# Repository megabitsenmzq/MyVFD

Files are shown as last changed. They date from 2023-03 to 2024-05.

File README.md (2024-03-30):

# MyVFD - A 9-Digit VFD Info Station ([Demo](https://www.youtube.com/watch?v=nbPkMLYwmgs))

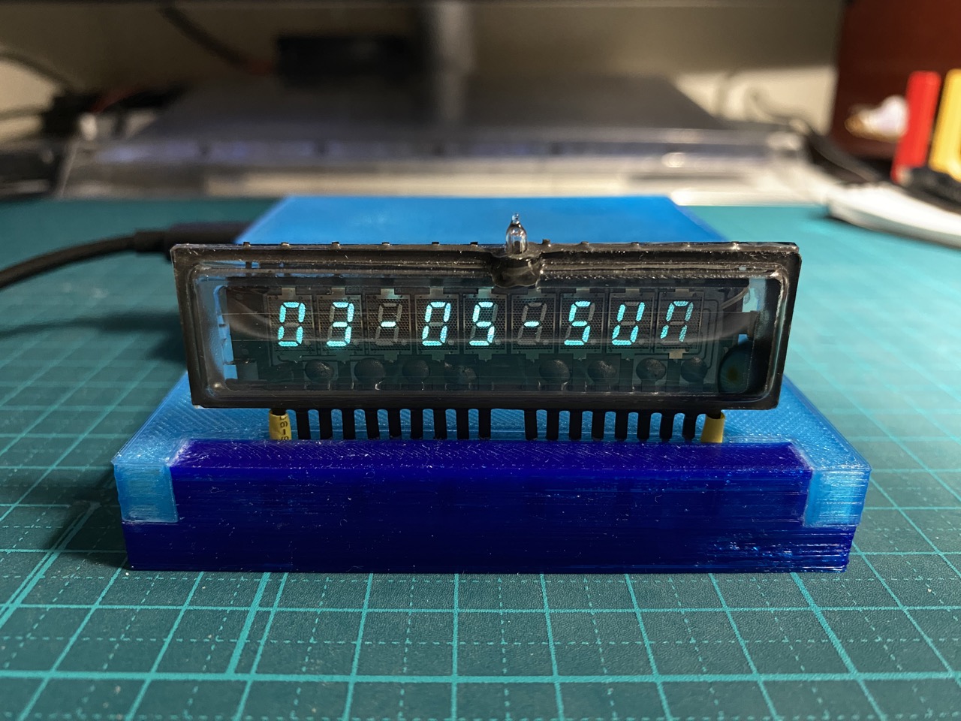
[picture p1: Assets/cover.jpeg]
Cover


Last year, I got an old Sharp EL-8109 calculator. Which uses a 9-digit Futaba 9-ST-08A VFD display. The calculator still works, but the shell is in bad shape, making it worth almost nothing. So I decided to use the screen inside to make something useful and look good.

This is the first hardware project I've ever made, so maybe I will do something wrong. Since I'm not a native English speaker, if you find any strange grammar, it's possibly my fault.

## What is a VFD

VFD means vacuum fluorescent display. Widely used in DVDs, radios, cassette decks, and so on. VFD screens look bright and visible from all angles. Making them the best choice for these devices. Today you can still see VFD screens in POS machines.

VFD

But LCD screens are becoming a better choice these days, and VFDs are no longer popular. Today, the green color of VFD screens gives them a retro vibe. If you want to see more beautiful VFDs, I recommend you watch this YouTube video by Posy: [VFD Displays](https://www.youtube.com/watch?v=PkPSDOjhxwM).

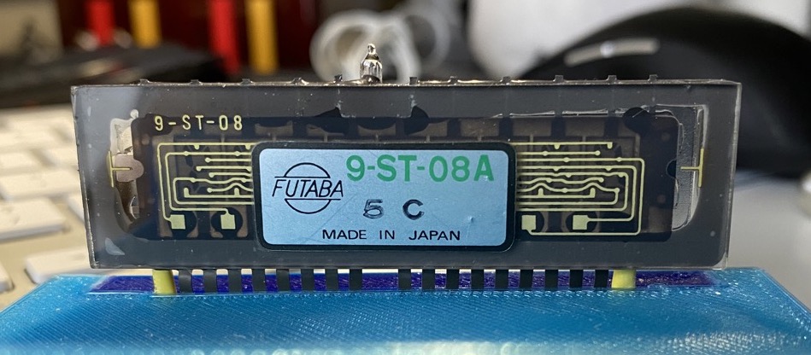
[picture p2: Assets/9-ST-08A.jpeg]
9-ST-08A


The screen 9-ST-08A was used in a variety of calculators around the 1970s, like Sanyo CX-8032 or Unisonic 1040. The company [Futaba (双葉電子工業株式会社)](https://www.futaba.co.jp/product/vfd) was Founded in 1948, making vacuum tubes and related things. They produced VFD screens until the end of 2021. Now they are moving on to newer display technologies.

## How to use the screen

This screen is too old, so it's almost impossible to find the datasheet. But most VFD screens are using the same structure. We can find out the pinout by ourselves.

This image from Futaba's website shows the basic structure of a VFD screen.

VFD Structure

VFD screens are very similar to vacuum tubes. Mainly, we have filaments, grids, and anodes. Filaments are very thin wires. They provide heat and a negative charge to the system. Anodes and grids provide high-voltage positive charge. Electrons will fly from filaments, pass the grids, and hit the anodes when they are both powered. Then you can see the beautiful green light from the phosphor.

VFD Structure 2

On a VFD screen. The pins on both sides are typically filament pins. They require a voltage of around 3V. And because we need a negative charge on the filament, the side near the positive pin will look dim. So it's best to power it with AC. This can ensure the screen lights evenly and extend its life. ~~Since I want to have a relatively small package on the final product. This time I will just use DC to power the screen.~~

I'm using a square wave as the AC power for the filament. First, I generate a 50% PWM signal from a pin. Then use a NOT gate to generate an inverted signal. Feed both signals to an H-bridge, there so we can have a square wave from about +5V to -5V.

Using a potentiometer to lower the voltage, adjust it to a proper value. When changing the voltage to the filament, you should keep an eye on the filament wires. If they start to glow, turn down the voltage immediately. Otherwise, the wires can start to melt and break. You might need to turn off all lights in your room to focus on this. You should let the voltage be just below the point which lets the filament glow.

After wiring the filament properly, we can start to take a look at other pins. Anodes and grids require a relatively high voltage. To provide this voltage, you need a step-up DC/DC converter. Connect the converter ground to the common ground, and use the high voltage to probe the pins. You need to connect both an anode pin and a grid pin to turn one segment on. Since I have a small screen that doesn't require such a high voltage to just light, I can use 5V for probing.

By probing you will know which pin is connected to which part of the screen. You can also check if there is a schematic printed behind the screen, like the image above.

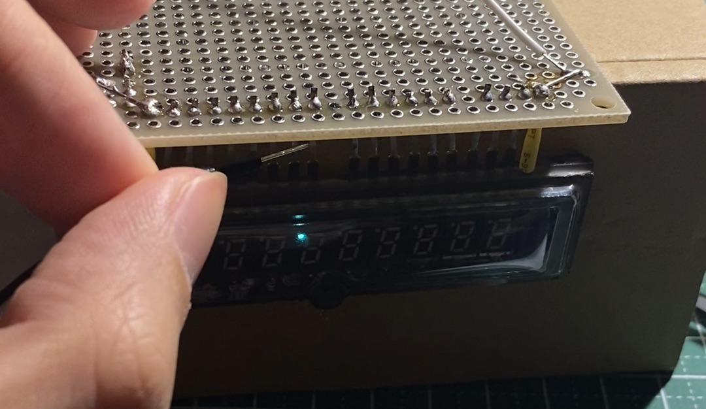
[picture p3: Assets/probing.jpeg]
Probing


## Build the circuit

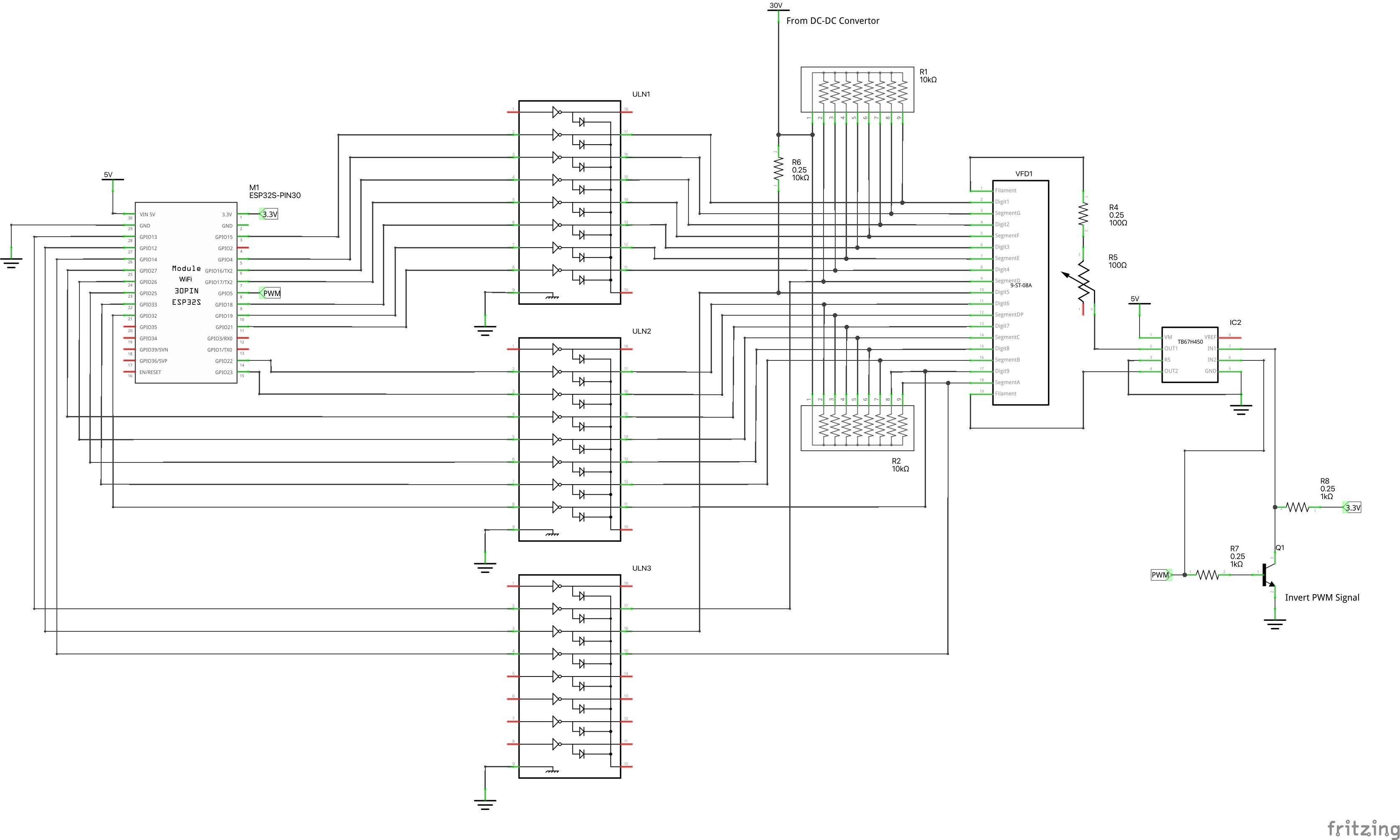
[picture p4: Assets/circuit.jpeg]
Circuit


In this circuit, I'm using Darlington Transistor Arrays (ULN2803) to control the screen. When the input pin of a transistor is low, the current goes through a 10K pull-up resistor and then the screen. When the input pin is high, it goes through the resistor and the transistor to the ground.

I have referenced [this](https://www.instructables.com/A-Simple-Driver-for-VFD-Displays/) design beforehand. In the schematic, it says the common pin of the ULN2803 should connect to the ground. However, after reading the datasheet and testing, I found this pin should not connect to anything. And the GND pin should be grounded.

I also found that the first transistor in the ULN2803 has a different behavior than others. When the input pin 1 is high, all the other transistors in the array will be turned on too. I don't understand why, but I can simply ignore the first pin. Tell me why if you know the reason.

On the ESP32 side. I'm using almost all the GPIO pins. but specifically left D2 behind. Because D2 is also connected to the onboard LED.

On the right side, you can see the AC power circuit. When the first time I made this project, I used to have DC power on the filament. Then I managed to find an easy way to do this, and the footprint is relatively small.

| Testing with the original board | Soldering | Soldering |
| --- | --- | --- |
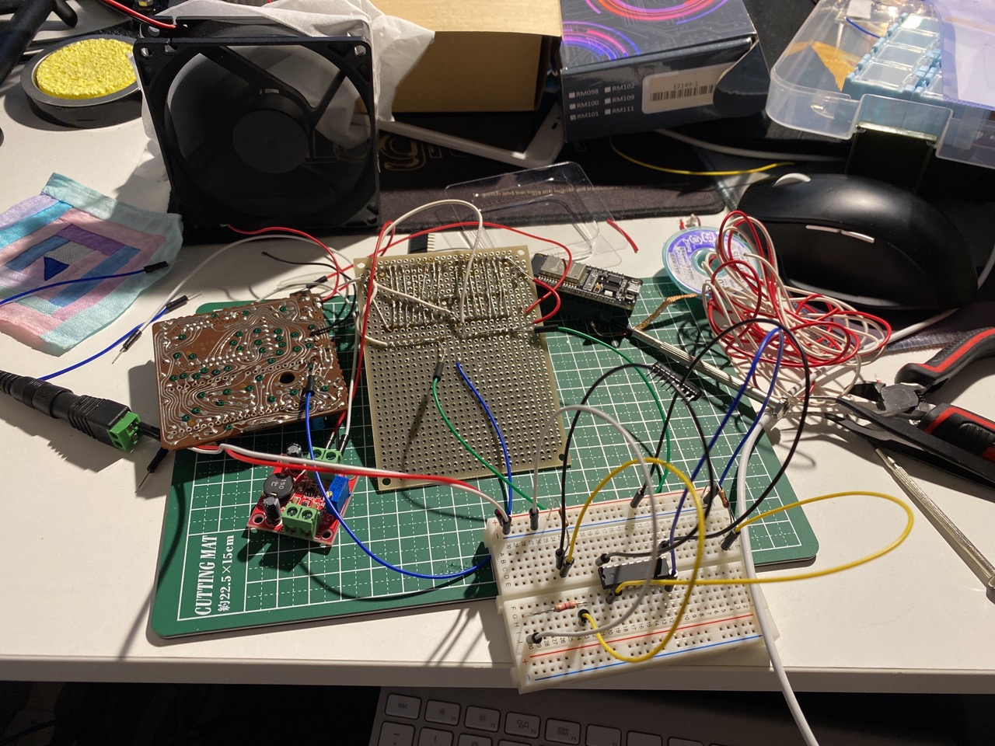
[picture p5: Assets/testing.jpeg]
testing
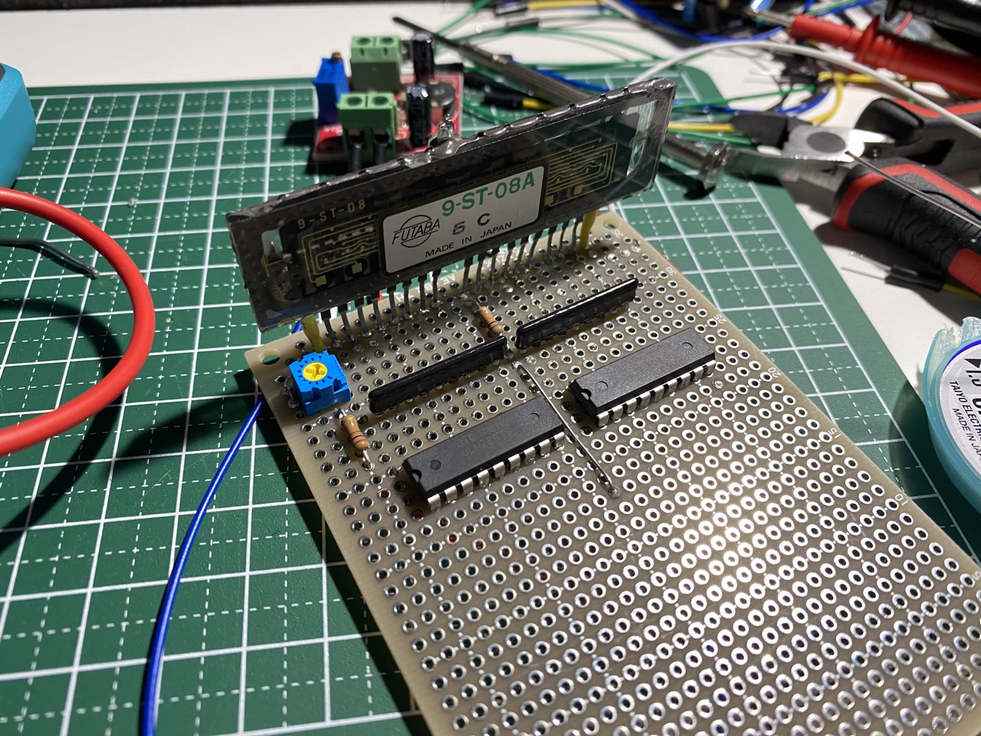
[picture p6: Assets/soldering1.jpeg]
soldering1
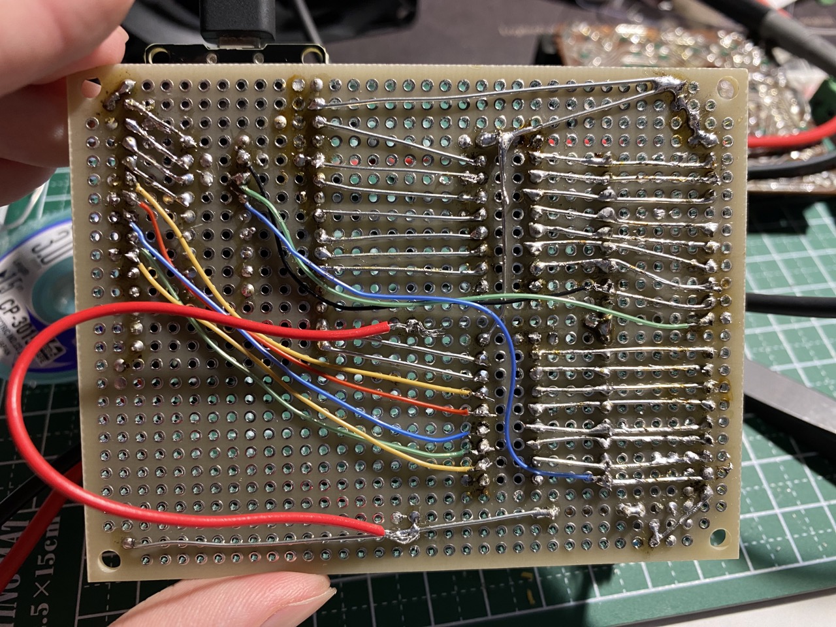
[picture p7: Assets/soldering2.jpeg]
soldering2
|  |  |  |

(The big red wire is for testing before using any high voltage.)

After the DC/DC converter soldered, I wrote a small program to test if there were any bad soldering. 

screen_testing

Let's see the final board.

| Top | Bottom | Side |
| --- | --- | --- |
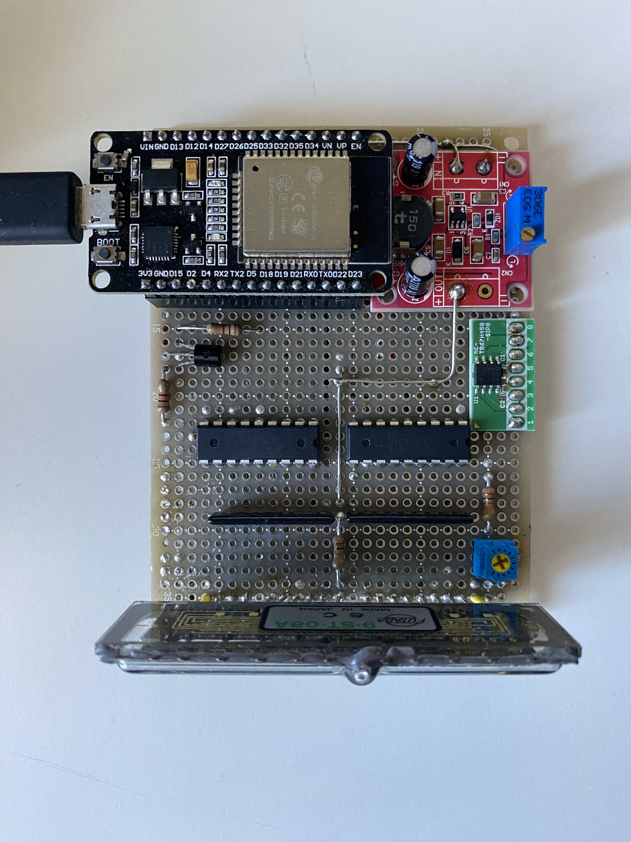
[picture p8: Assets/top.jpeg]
top
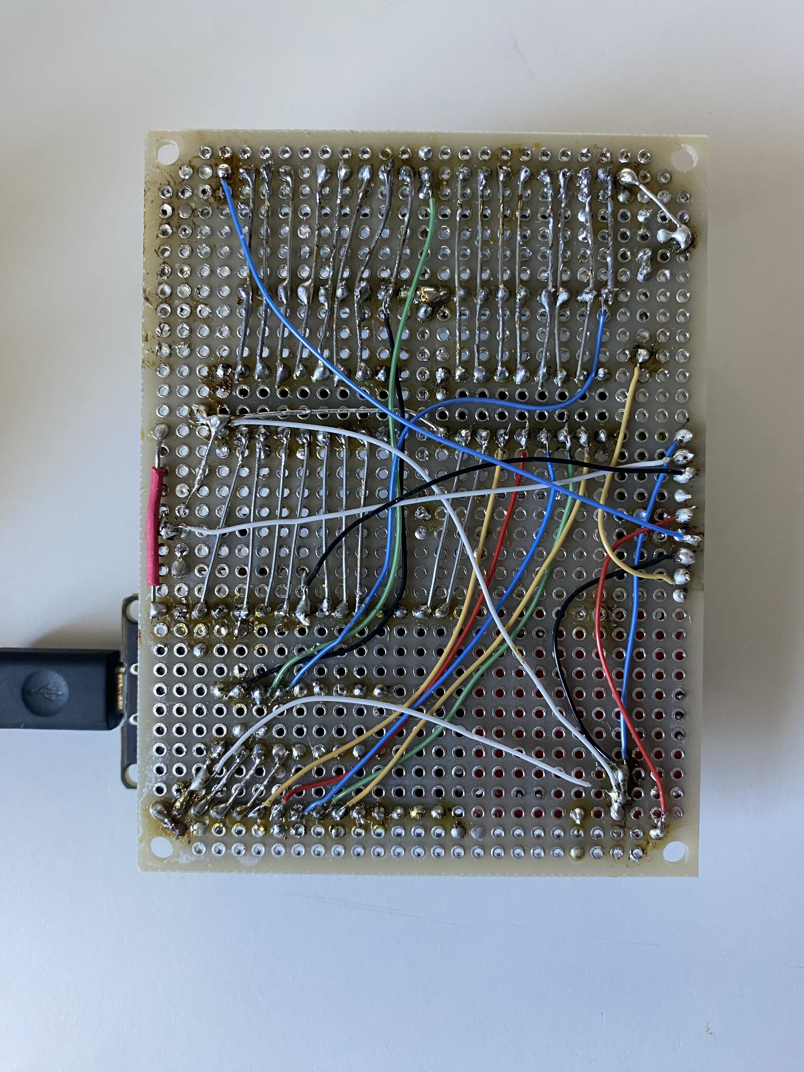
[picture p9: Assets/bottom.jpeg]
bottom
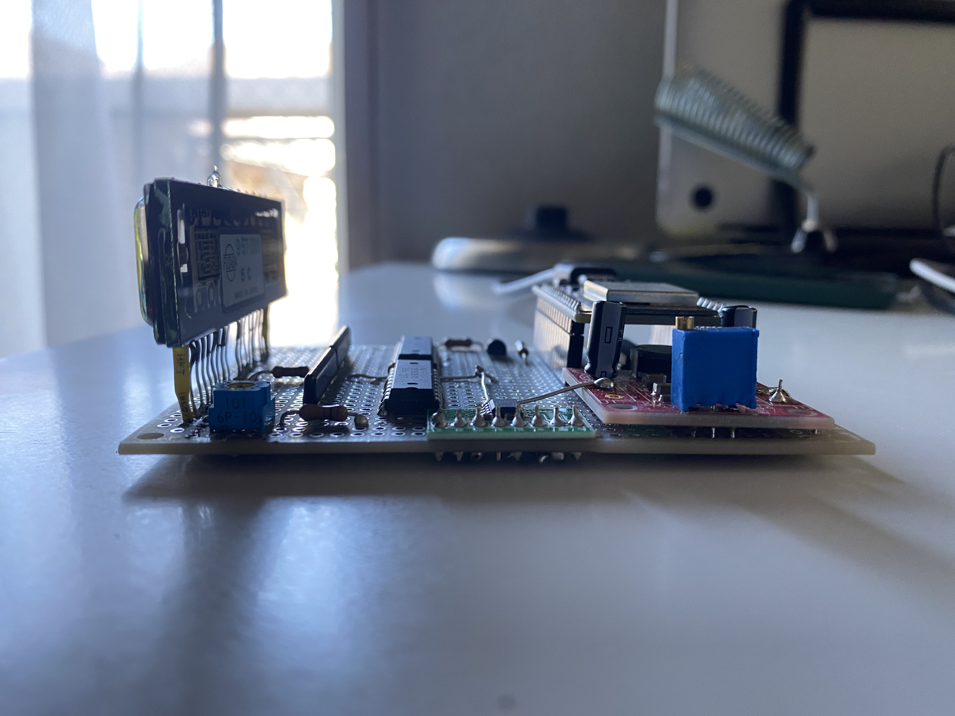
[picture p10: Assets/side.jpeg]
side
|  |  |  |

## Programming the ESP32

To control the screen. I'm using a library called [SevSeg](https://github.com/DeanIsMe/SevSeg). It was made to control 7-Seg LED displays but also works on VFD. Because my screen has 9 digits, I need to modify the code to use more than 8 digits. And this library does not support some of the alphabet, so I added the missing parts by myself.

After a week of programming. My VFD info station now supports:

- Date / Time (Sync with NTP server at the start.)
- Current Temperature / Max Temperature / Min Temperature (From OpenWeather.)
- Custom Text (Set from the web UI.)
- Random Number Generator (Set from the web UI.)

And my code is structured so you can add new features to the code easily.

Because ESP32 has 2 cores, I created separate FreeRTOS tasks for them. I specifically use core 1 for refreshing the screen, and core 0 for other things. So network traffic won't interrupt screen refreshing.

To use my code, you need to create a "secret.h" file from the template. Then input your wifi SSID, password, OpenWeather API key, and location info.

If everything is set correctly, you will see the IP address on the screen after it is connected. The screen will change between date/time and weather info. You can access the IP address to control it from the web UI. 

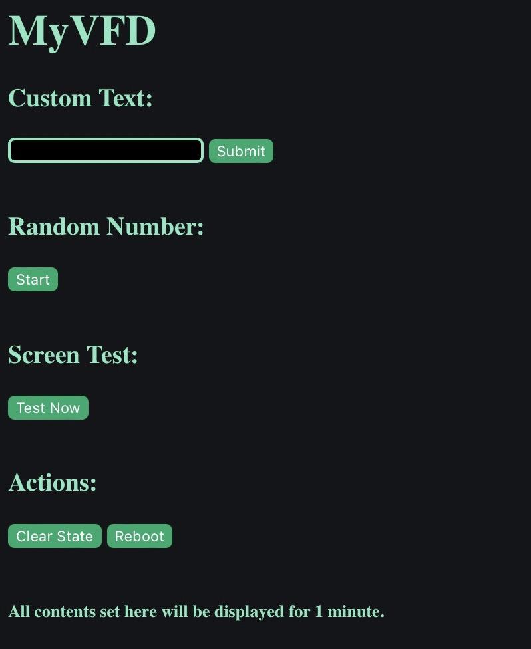
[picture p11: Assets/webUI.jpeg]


## Make a shell

Finally, to cover my bad soldering, I need a shell for the board. This time I'm using FreeCAD. After tons of prototypes on my 3D printer, I got a reasonably good final result.

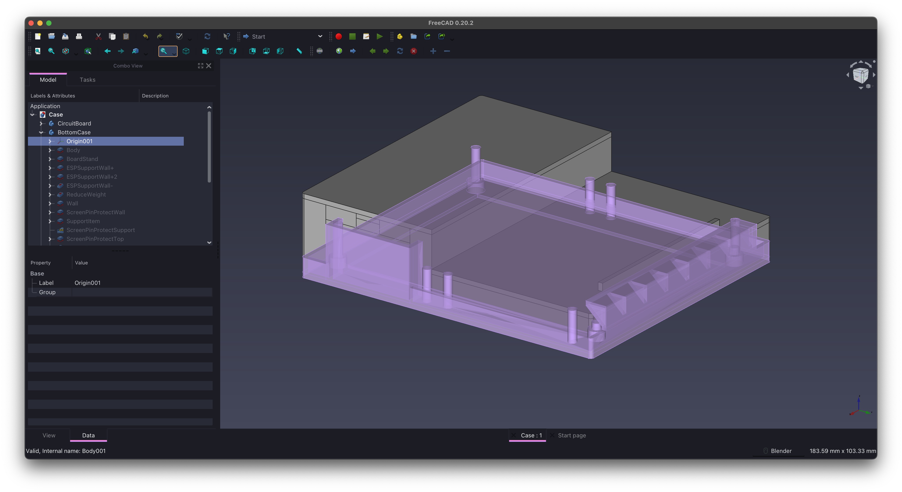
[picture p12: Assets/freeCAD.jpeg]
freeCAD


printing

After a month of hard work, I finally finished my first hardware project. I uploaded a [demo](https://www.youtube.com/watch?v=nbPkMLYwmgs) on YouTube, you can check it out. Hope you like it. Follow me on social media for my other projects. See you next time.

References:

[A Simple Driver for VFD Displays](https://www.instructables.com/A-Simple-Driver-for-VFD-Displays/)

[Arduino VFD Display Clock Tutorial - a Guide to VFD Displays](https://www.instructables.com/Arduino-VFD-Display-Clock-Tutorial-A-Guide-To-VFD-/)

[Arduinoを使ったVFD時計](https://elchika.com/article/81006b73-b0ff-498c-a89d-bc5b85f340b5/)

[Driving a VFD with MAX7219 (and Arduino)](https://www.hackster.io/wiresauce/driving-a-vfd-with-max7219-and-arduino-b01f0c)

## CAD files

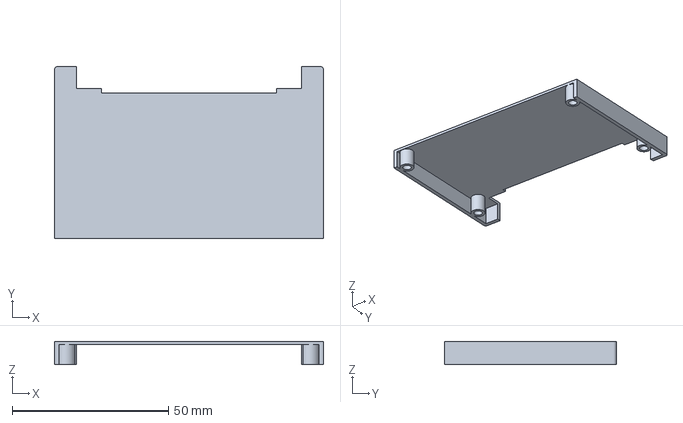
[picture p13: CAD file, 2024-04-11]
CAD/TopFront-Final.3mf
86.0 x 55.0 x 7.50 mm

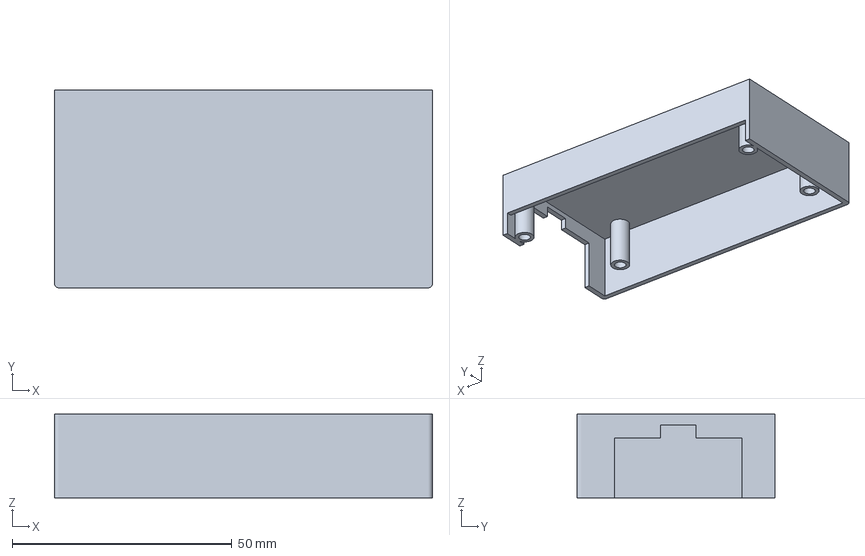
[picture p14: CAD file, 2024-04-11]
CAD/TopBack-Final.3mf
86.0 x 45.0 x 19.0 mm

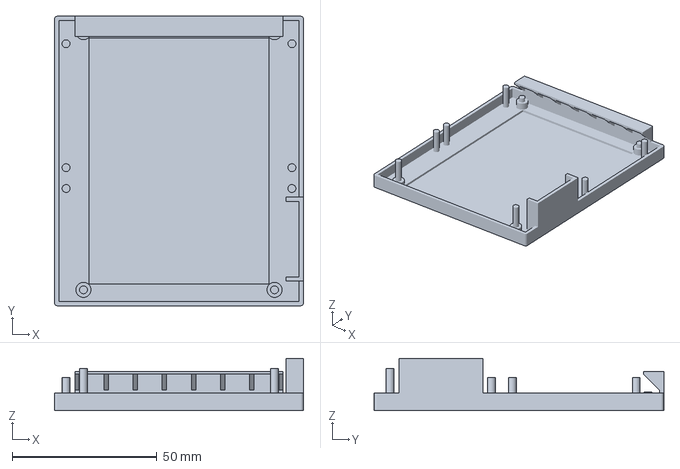
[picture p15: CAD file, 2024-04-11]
CAD/Bottom-Final.3mf
86.0 x 100.0 x 18.1 mm

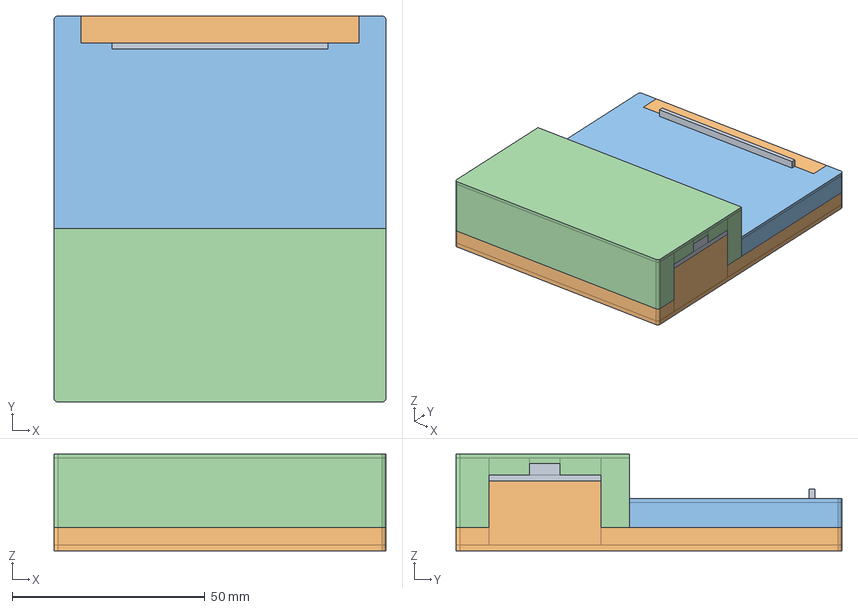
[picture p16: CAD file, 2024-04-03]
CAD/Case.FCStd
86.0 x 100.0 x 25.1 mm
CircuitBoard
BottomCase
TopFrontCase
TopBackCase

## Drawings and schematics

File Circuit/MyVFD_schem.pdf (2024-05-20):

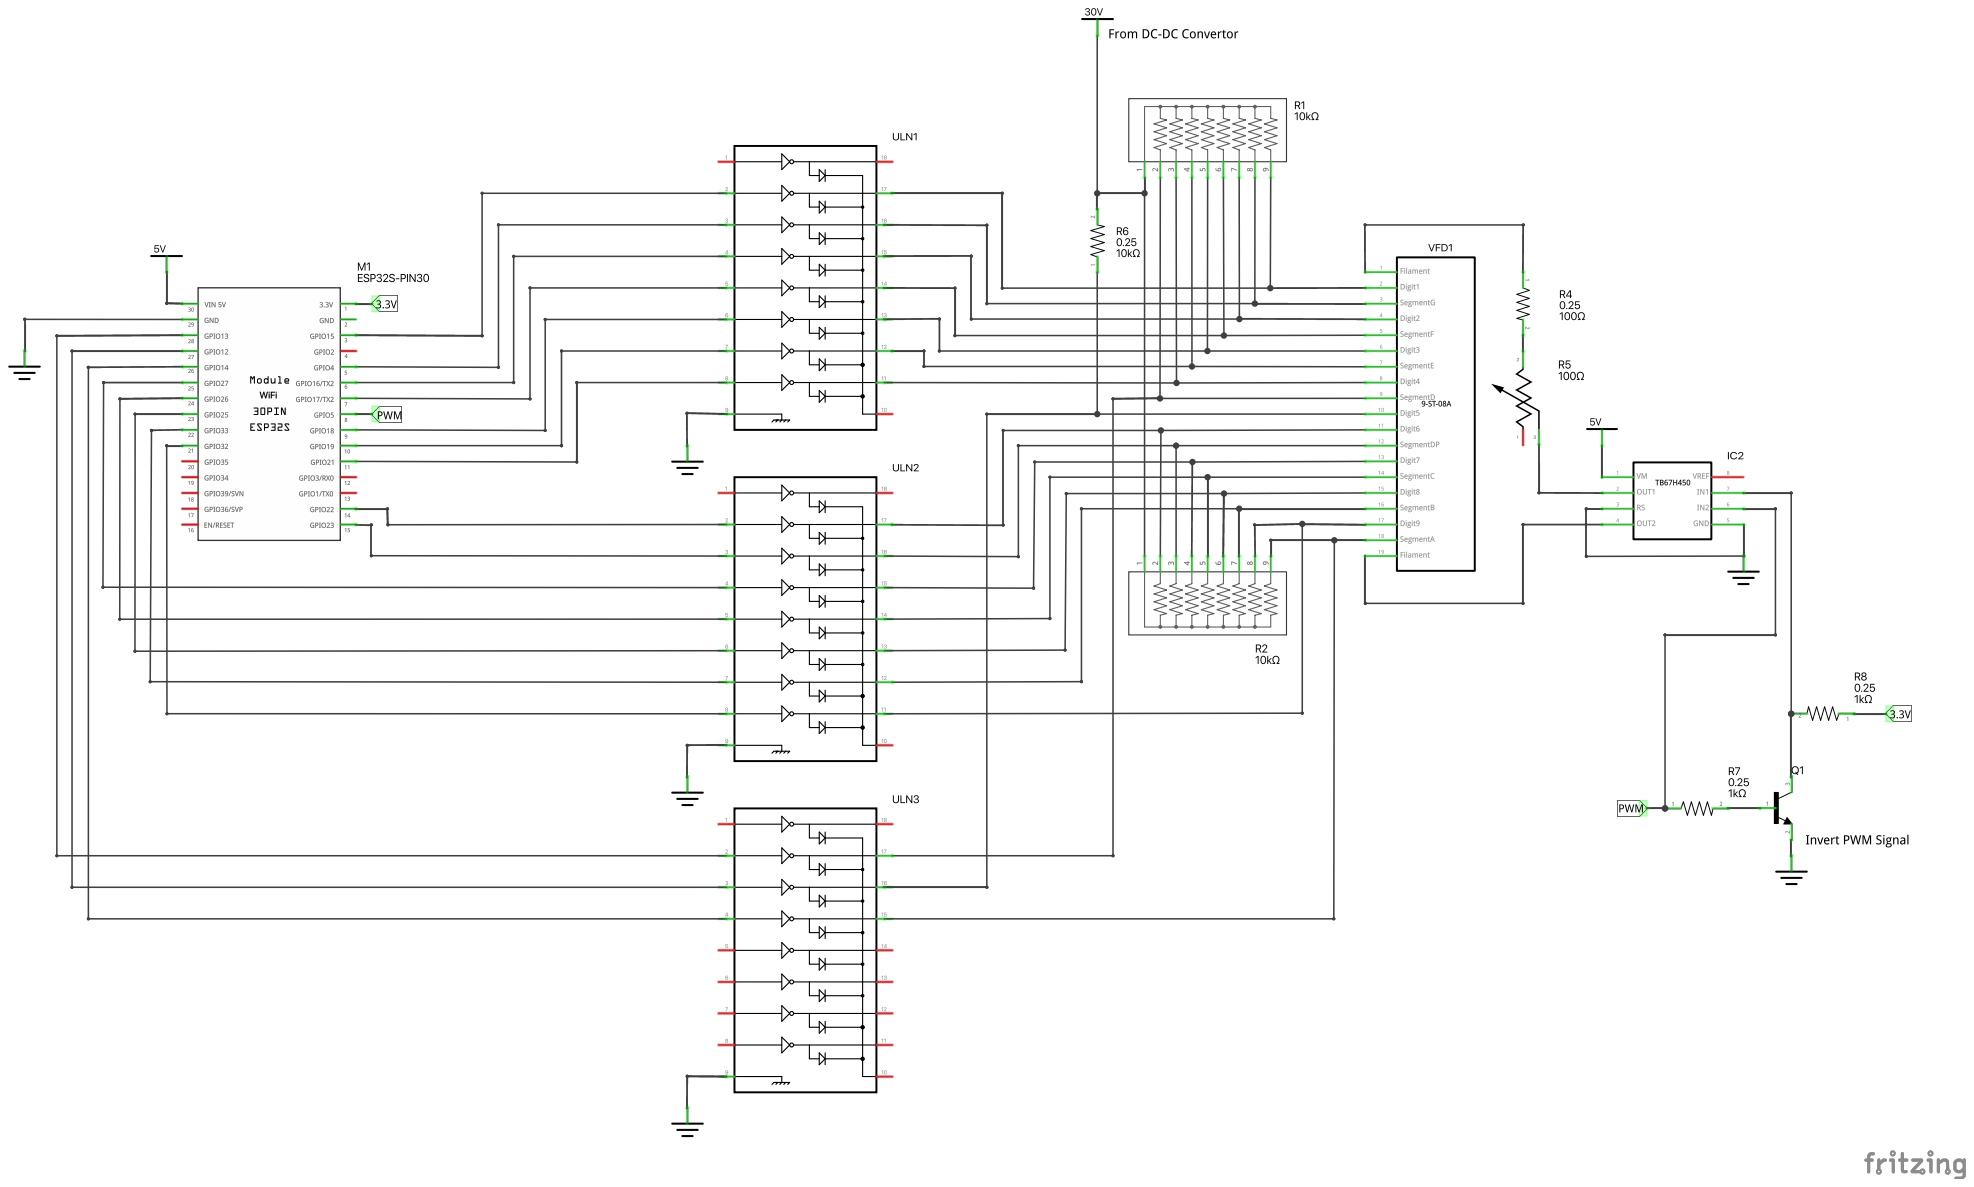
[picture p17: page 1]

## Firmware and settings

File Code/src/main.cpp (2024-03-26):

#include "core0Loop.h"
#include "core1Loop.h"
#include <WiFi.h>

// Multi Core
TaskHandle_t Core0Task[1];
TaskHandle_t Core1Task[1];

void core0a(void *args) {
  while (1) {
    delay(1); // Wait for watchdog.
    core0Loop();
  }
}

void core1a(void *args) {
  while (1) {
    core1Loop();
  }
}

void setup() {
  Serial.begin(115200);

  // LED
  ledcSetup(0, 4096, 8);
  ledcAttachPin(LED_PIN, 0);

  // WiFi
  WiFi.begin(WIFI_SSID, WIFI_PASSWORD);

  // SevSeg
  sevseg.begin(hardwareConfig, numDigits, digitPins, segmentPins, resistorsOnSegments, updateWithDelays);
  sevseg.setBrightness(100);

  // Multi Core
  xTaskCreatePinnedToCore(core0a, "Core0a", 1024*8, NULL, 1, &Core0Task[0], 0);
  xTaskCreatePinnedToCore(core1a, "Core1a", 1024*4, NULL, 1, &Core1Task[0], 1);

  // Filament Power Signal
  pinMode(5, OUTPUT);
  analogWrite(5, 128);
}

void loop() {
  vTaskDelete(nullptr); // Remove loop from tasks. Use FreeRTOS tasks instead.
}

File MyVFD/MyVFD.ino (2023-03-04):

#include <Arduino.h>
#include <WiFi.h>
#include "src/SevSeg/SevSeg.h"
#include "Bitmap.h"
#include "Secret.h"
#include "WebServer.h"
#include "DateTime.h"
#include "Weather.h"
#include "Random.h"

// LED
#define LED_PIN 2 // On board LED.
#define LED_BRIGHTNESS 64

// SveSeg
SevSeg sevseg;
const byte hardwareConfig = P_TRANSISTORS;
const byte numDigits = 9;
const byte digitPins[] = {15, 16, 18, 21, 12, 22, 27, 25, 32};
const byte segmentPins[] = {14, 33, 26, 13, 19, 17, 4, 23};
const bool resistorsOnSegments = false;
const bool updateWithDelays = false;

// Multi Core
TaskHandle_t Core0Task[1];
TaskHandle_t Core1Task[1];

// Display Mode
enum DisplayMode {ipAddress, currentDate, currentTime, currentTemp, highTemp, lowTemp, customText, randomNumber, screenTest};
DisplayMode modeCycle[] = {currentDate, currentTime, currentTemp, highTemp, lowTemp};
DisplayMode currentMode = ipAddress;
int currentModeIndex = 0;
bool showLoadingAnimation = true;

// Modules
WebServer webServer = WebServer();
DateTime dateTime = DateTime();
Weather weather = Weather();
Random randomAnimator = Random();

// Loading Animation
const long loadingAnimtaionInterval = 100;
unsigned long loadingAnimationTimeStamp = 0;
int loadingAnimationIndex = 0;

// Screen test animation.
const int screenTestInterval = 1000;
unsigned long screenTestTimeStamp = 0;
int screenTestingAnimationIndex = 0;

void setup() {
  Serial.begin(115200);

  // LED
  ledcSetup(0, 4096, 8);
  ledcAttachPin(LED_PIN, 0);

  // WiFi
  WiFi.begin(WIFI_SSID, WIFI_PASSWORD);

  // SevSeg
  sevseg.begin(hardwareConfig, numDigits, digitPins, segmentPins, resistorsOnSegments, updateWithDelays);
  sevseg.setBrightness(120);

  // Multi Core
  xTaskCreatePinnedToCore(Core0a, "Core0a", 1024*8, NULL, 1, &Core0Task[0], 0); 
  xTaskCreatePinnedToCore(Core1a, "Core1a", 1024*4, NULL, 1, &Core1Task[0], 1); 
}

void loop() {
  vTaskDelete(nullptr); // Remove loop from tasks. Use FreeRTOS tasks instead.
}

void Core0a(void *args) {
  while (1) {
    delay(1); // Wait for watchdog.
    core0Loop();
  }
}

void Core1a(void *args) {
  while (1) {
    core1Loop();
  }
}

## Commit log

2023-02-12 Case draft.
    [Case.FCStd]
2023-02-12 Case Version 2.
    [Case.FCStd]
2023-02-12 Modify case design.
    [Case.FCStd]
2023-02-13 Add more pillars.
    [Case.FCStd]
2023-02-13 Add test file.
    [PillarToleranceTest.FCStd]
2023-02-13 Update design.
    [Case.FCStd]
2023-02-20 Update sizes.
    [Case.FCStd, PillarToleranceTest.FCStd]
2023-02-20 Fix constraints.
    [Case.FCStd]
2023-02-20 Modify some values and fix the sketch with the Link fork.
    [Case.FCStd]
2023-02-21 Final CAD files.
    [Bottom-Final.stl, Case.FCStd, PillarToleranceTest.FCStd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]
2023-02-22 Add support for onboard LED.
2023-02-26 Use internal PWM.
2023-03-01 Add circuit schematic files.
    [MyVFD.fzz]
2023-03-02 Remove custom text and minor fixes.
    [Core1Loop.ino, MyVFD.ino, Weather.cpp]
2023-03-04 Using ESP32's true random number.
2024-03-25 Add filament power signal.
2024-03-25 Update scheme.
    [MyVFD.fzz]
2024-04-03 Update modal.
    [Case.FCStd]
2024-05-20 Update circuit.
    [MyVFD.fzz]
